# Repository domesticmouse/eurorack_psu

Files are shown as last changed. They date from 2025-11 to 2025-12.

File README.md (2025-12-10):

# Eurorack PSU

A simple 6HP +-12V Eurorack PSU, based on Winterbloom's [Micronova][].
See [EurorRack dimensions][] for faceplate dimensions.

[Micronova]: https://winterbloom.com/shop/micronova/
[EurorRack dimensions]: https://midisoft.de/EuroRackDimensions/EuroRack_Dimensions.html

## Parts

| LCSC Part | Manufacturer | Description |
| --- | --- | --- |
| [C72487](https://www.lcsc.com/product-detail/C72487.html) | ROQANG | CAP ALUM 10uF ±20% 50V SMD |
| [C3001207](https://www.lcsc.com/product-detail/C3001207.html) | ROQANG | CAP ALUM 22uF ±20% 25V SMD |
| [C1779](https://www.lcsc.com/product-detail/C1779.html) | Samsung Electro-Mechanics | CAP CER 4.7uF 25V X5R 0805 |
| [C3151829](https://www.lcsc.com/product-detail/C3151829.html) | ROQANG | CAP ALUM 100uF ±20% 50V SMD |
| [c701168](https://www.lcsc.com/product-detail/C701168.html) | muRata | FIXED IND 10uH 800mA 190mΩ SMD,3x3mm |
| [c64982](https://www.lcsc.com/product-detail/C64982.html) | MDD(Microdiode Semiconductor) | DIODE SCHOTTKY 40V SMA(DO-214AC) |
| [C5369648](https://www.lcsc.com/product-detail/C5369648.html) | YLPTEC | K7812-1000R3 SIP,11.5x7.6mm AC DC Configurable Power Supply Modules RoHS |
| [C22355851](https://www.lcsc.com/product-detail/C22355851.html) | DOWO | VARISTOR 18V 150A 1206 |
| [C142805](https://www.lcsc.com/product-detail/C142805.html) | Littelfuse | 24V 1.5A 20A 3A 40mΩ 1812 PTC Resettable Fuses RoHS |
| [C27834](https://www.lcsc.com/product-detail/C27834.html) | UNI-ROYAL | RES 5.1kΩ ±1% 125mW 0805 |
| [C84256](https://www.lcsc.com/product-detail/C84256.html) | NATIONSTAR | LED RED 0805 SMD |
| [C22373734](https://www.lcsc.com/product-detail/C22373734.html) | Hynetek | USB-C Power Receiver Controller 100W |
| [C1744](https://www.lcsc.com/product-detail/C1744.html) | FH | 50V 4.7nF X7R ±10% 0805 |
| [C1726](https://www.lcsc.com/product-detail/C1726.html) | FH | 50V 20nF X7R ±10% 0805 |
| [C52711227](https://www.lcsc.com/product-detail/C52711227.html) | HH | USB 2.0 5A Surface Mount Vertical 16P Female Type-C USB Connector |

## USB Type C PD Datasheets

- [C52711227 USB Connector](https://www.lcsc.com/datasheet/C52711227.pdf)
- [C22373734 USB Type-C Power Delivery Sink Controller](https://www.lcsc.com/datasheet/C22373734.pdf)

## Kicanvas

- [PSU](https://kicanvas.org/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)
- [Faceplate](https://kicanvas.org/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)

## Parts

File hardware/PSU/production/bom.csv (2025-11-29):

Designator | Footprint | Quantity | Value | LCSC Part #
C1 | CP_Elec_6.3x7.7 | 1 | 100uF 50v | C3151829
C2, C3 | CP_Elec_5x5.4 | 2 | 10uF 50v | C72487
C4, C5 | CP_Elec_5x5.4 | 2 | 22uF 25v | C3001207
C6, C7 | 0805 | 2 | 4.7uF 25v | C1779
CN1, CN2 | CONN-TH_B2B-PH-K-S | 2 | JST PH 2 pin male | C131337
D1 | D_SMA_Handsoldering | 1 | Barrier | C64982
D2, D3, D4 | LED_D3.0mm | 3 | LED | C84256
F1 | 1812 | 1 | 1.5A 24V | C142805
J1, J2 | IDC-Header_2x05_P2.54mm_Vertical | 2 | IDC 2x5 male
L1 | L_muRata_LQH3NPZ100MMEL_HandSolder | 1 | 10uH 800mA | C701168
R1, R2, R3 | 0805 | 3 | 5.1k | C27834
RV1 | 1206 | 1 | MOV 18v | C22355851
TP1, TP2 | TestPoint_Keystone_5000-5004_Miniature | 2 | GND
TP3 | TestPoint_Keystone_5000-5004_Miniature | 1 | +12v
TP4 | TestPoint_Keystone_5000-5004_Miniature | 1 | -12v
TP5 | TestPoint_Keystone_5000-5004_Miniature | 1 | +15v
U1, U2 | PWRM-TH_K7812-1000R3 | 2 | K7812-1000R3 | C5369648

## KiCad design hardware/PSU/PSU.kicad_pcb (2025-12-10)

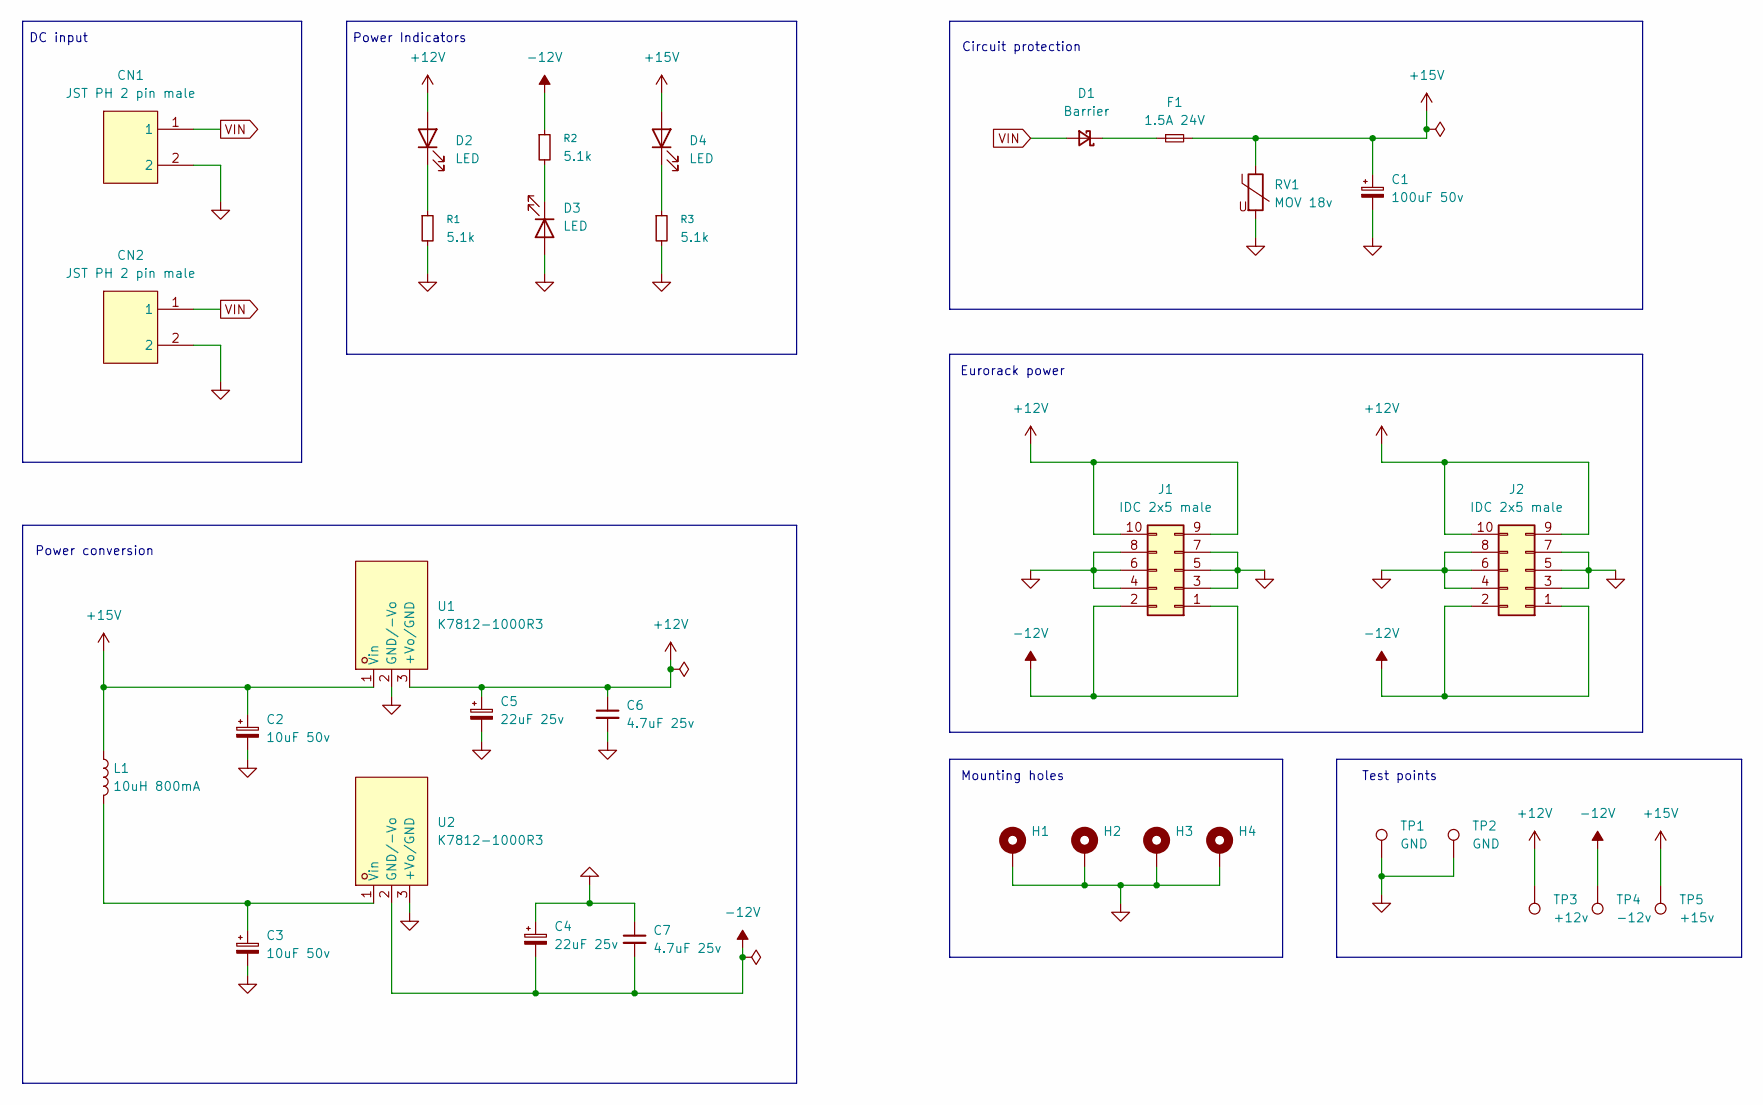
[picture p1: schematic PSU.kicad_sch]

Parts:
C1: 100uF 50v; CP_Elec_6.3x7.7; LCSC Part C3151829
C2, C3: 10uF 50v; CP_Elec_5x5.4; LCSC Part C72487
C4, C5: 22uF 25v; CP_Elec_5x5.4; LCSC Part C3001207
C6, C7: 4.7uF 25v; C_0805_2012Metric_Pad1.18x1.45mm_HandSolder; LCSC Part C1779
CN1, CN2: JST PH 2 pin male; CONN-TH_B2B-PH-K-S; LCSC Part C131337
D1: Barrier; D_SMA_Handsoldering; LCSC Part C64982
D2, D3, D4: LED; LED_D3.0mm; LCSC Part C84256
F1: 1.5A 24V; Fuse_1812_4532Metric_Pad1.30x3.40mm_HandSolder; LCSC Part C142805
H1, H2, H3, H4: MountingHole_3.2mm_M3_Pad
J1, J2: IDC 2x5 male; IDC-Header_2x05_P2.54mm_Vertical
L1: 10uH 800mA; L_muRata_LQH3NPZ100MMEL_HandSolder; LCSC Part C701168
R1, R2, R3: 5.1k; R_0805_2012Metric_Pad1.20x1.40mm_HandSolder; LCSC Part C27834
RV1: MOV 18v; R_1206_3216Metric_Pad1.30x1.75mm_HandSolder; LCSC Part C22355851
TP1, TP2: GND; TestPoint_Keystone_5000-5004_Miniature
TP3: +12v; TestPoint_Keystone_5000-5004_Miniature
TP4: -12v; TestPoint_Keystone_5000-5004_Miniature
TP5: +15v; TestPoint_Keystone_5000-5004_Miniature
U1, U2: K7812-1000R3; PWRM-TH_K7812-1000R3; LCSC Part C5369648

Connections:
+12V: C5.1, C6.1, D2.2 (A), J1.9, J1.10, J2.9, J2.10, TP3.1, U1.3 (+Vo/GND)
+15V: C1.1, C2.1, D4.2 (A), F1.2, L1.1, RV1.1, TP5.1, U1.1 (Vin)
-12V: C4.2, C7.2, J1.1, J1.2, J2.1, J2.2, R2.1, TP4.1, U2.2 (GND/-Vo)
GND: C1.2, C2.2, C3.2, C4.1, C5.2, C6.2, C7.1, CN1.2, CN2.2, D3.2 (A), H1.1, H2.1, H3.1, H4.1, J1.3, J1.4, J1.5, J1.6, J1.7, J1.8, J2.3, J2.4, J2.5, J2.6, J2.7, J2.8, R1.2, R3.2, RV1.2, TP1.1, TP2.1, U1.2 (GND/-Vo), U2.3 (+Vo/GND)
unnamed: D1.1 (K), F1.1
unnamed: D2.1 (K), R1.1
unnamed: D3.1 (K), R2.2
unnamed: D4.1 (K), R3.1
unnamed: C3.1, L1.2, U2.1 (Vin)
VIN: CN1.1, CN2.1, D1.2 (A)

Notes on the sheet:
Eurorack power
Circuit protection
Power Indicators
Test points
Mounting holes
DC input
Power conversion

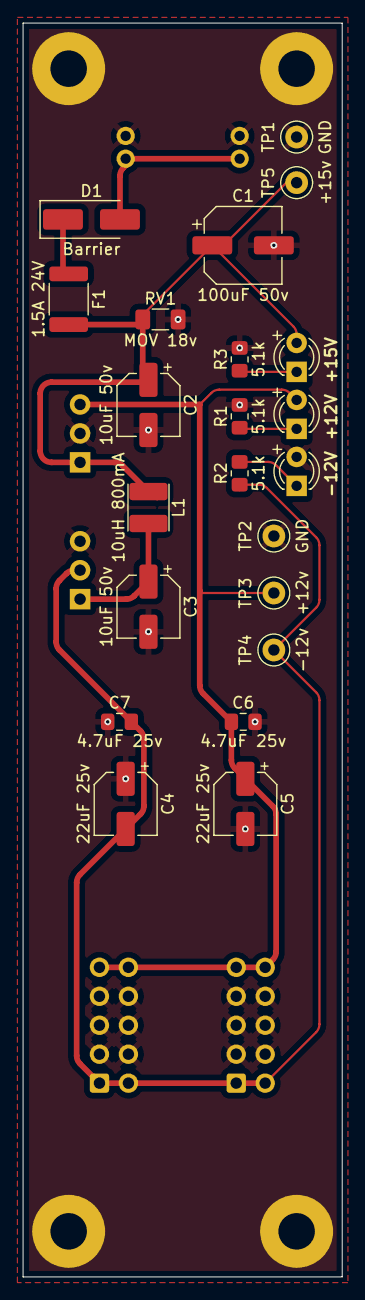
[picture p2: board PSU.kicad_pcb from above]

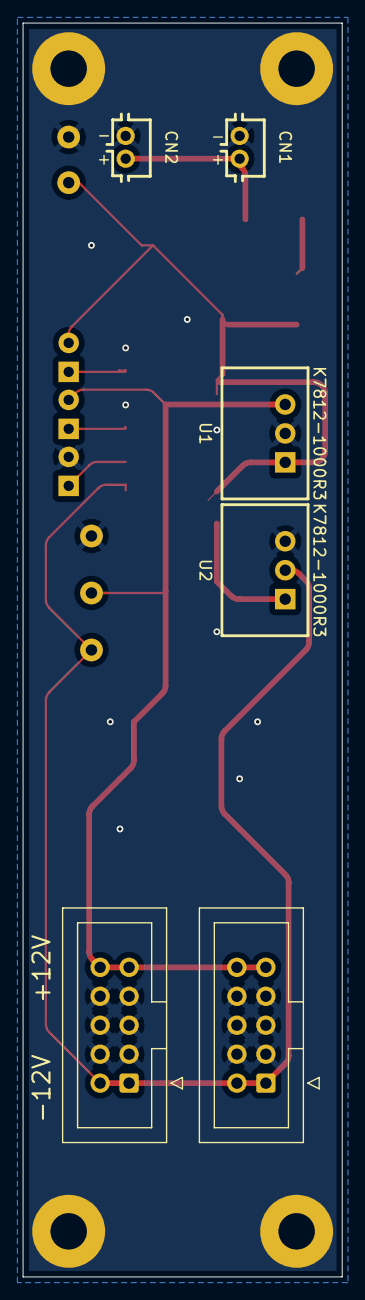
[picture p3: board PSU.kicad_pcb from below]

Board: 2 copper layers, 28.0 x 110.0 mm, 32 parts (6 on the bottom side), 10 nets.

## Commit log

2025-11-28 Initial KiCad files
    [PSU.kicad_pcb, PSU.kicad_sch]
2025-11-28 Initial schematic
    [PSU.kicad_sch]
2025-11-28 Initial board layout
    [PSU.kicad_pcb, PSU.kicad_sch]
2025-11-28 Add test points
    [PSU.kicad_pcb, PSU.kicad_sch]
2025-11-29 Use 3mm LEDs instead
    [PSU.kicad_pcb, PSU.kicad_sch]
2025-11-29 Build the production file
    [bom.csv, designators.csv, positions.csv]
2025-11-30 faceplate init
    [faceplate.kicad_pcb, faceplate.kicad_sch]
2025-11-30 Update Faceplate
    [faceplate.kicad_pcb]
2025-12-01 Update faceplate and hit print
    [designators.csv, faceplate.kicad_pcb]
2025-12-02 Add + markers
    [PSU.kicad_pcb]
2025-12-10 Add more labels to the power input connections
    [PSU.kicad_pcb]
